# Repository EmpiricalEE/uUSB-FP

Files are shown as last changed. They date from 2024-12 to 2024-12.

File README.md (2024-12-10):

# Joulescope JS220 uUSB Front Panel

> ⚠️ This is a **read-only** mirror of a private SVN repository. See the [Product Page](https://www.tindie.com/products/empirical-ee/uusb-front-panel/) on Tindie.

The uUSB FP is a versatile panel for the [Joulescope JS220](https://www.joulescope.com/products/js220-joulescope-precision-energy-analyzer) power analyser that enables power measurement of any USB device.

## Key Features

- Multiple USB connector types supported:
    - USB Type-C
    - USB Type-A
    - Micro USB
    - Screw terminals for custom connections
- Supports any combination of input terminal and output terminal
- Compatible with Joulescope JS220
- Supports USB 2.0 High Speed (HS) data pass-through with minor performance impact

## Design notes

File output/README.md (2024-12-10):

## Introduction

- Name: BP1 (aka `Joulescope 220 Front Panel for USB powered loads`)
- Version:
	- PCB: v241112
	- BOM: Rev C
- Purpose: PCB manufacture and assembly

## PCB Manufacturing Specifications

- IPC-6011: Class 2
- Base Material: FR-4
- PCB Thickness: 1.6 mm ± 10 %
- Outline tolerance: 0.2 mm
- Layers: 4
- Outer Copper Weight: 1 oz
- Inner Copper Weight: 0.5 oz
- Impedance Control: No requirement
- PCB Color: Black
- Silkscreen Colour: White
- Via Covering: Tented
- Surface Finish: HASL (with lead)
- Mark on PCB on the rear (JLCPCB Remove Mark)

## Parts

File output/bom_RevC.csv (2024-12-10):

Reference | Value | Datasheet | Footprint | Qty | DNP | Description | MPN | Manufacturer | Order Code | Supplier | Critical
J1 | JS220 | https://mm.digikey.com/Volume0/opasdata/d220001/medias/docus/6129/tsm-1xx-xx-xxx-xx-x-xxx-x-mkt.pdf | Joulescope:JS220 | 1 |  | Joulescope 220 front panel outline and connector | TSM-103-01-S-DV-A | Samtec Inc. | TSM-103-01-S-DV-A-ND | Digi-Key
J2 | USB_B_In | https://www.cuidevices.com/product/resource/uj2-bv-1-th.pdf | Becquerel:USB_B_CUI_Devices_UJ2-BV-1-TH_Vertical | 1 |  | USB Type B connector | UJ2-BV-1-TH | CUI Devices | 102-4000-ND | Digi-Key
J3 | USB_B_Micro_In | https://gct.co/files/specs/usb3145-spec.pdf | Becquerel:USB_Micro-B_GCT_USB3145-30-1-A_Vertical | 1 |  | USB Micro Type B connector | USB3145-30-1-A | GCT | 2073-USB3145-30-1-ACT-ND | Digi-Key
J4 | USB_C_In | https://mm.digikey.com/Volume0/opasdata/d220001/medias/docus/5561/USB4145%20-%20Product%20Drawing.pdf | Becquerel:USB_C_Receptacle_GCT_USB4115-03-C | 1 |  | USB 2.0-only 24P Type-C Receptacle connector | UJ20-C-V-C-3-SMT-TR | Same Sky | 2223-UJ20-C-V-C-3-SMT-TR-ND | Digi-Key
J5 | Screw_In | https://www.we-online.com/katalog/datasheet/6912109100xx.pdf | Becquerel:TerminalBlock_Wuerth_691210910004-2.54-4P_1x04_P2.54mm_Horizontal | 1 |  | Generic screw terminal, single row, 01x04, script generated (kicad-library-utils/schlib/autogen/connector/) | 691210910004 | Würth Elektronik | 732-691210910004-ND | Digi-Key
J6 | USB_A_Out | https://app.adam-tech.com/products/download/data_sheet/195863/usb-a-s-vt-data-sheet.pdf | Becquerel:USB_A_Adam_Tech_USB-A-S-VT_Vertical | 1 |  | USB Type A connector | USB-A-S-VT | Adam Tech | 2057-USB-A-S-VT-ND | Digi-Key
J7 | USB_AB_Micro_Out | https://gct.co/files/specs/usb3106-spec.pdf | Becquerel:USB_Micro-AB_GCT_USB3106-30-0230-A_Vertical | 1 |  | USB Micro Type B connector | USB3106-30-0230-A | GCT | 2073-USB3106-30-0230-ACT-ND | Digi-Key
J8 | USB_C_Out | https://mm.digikey.com/Volume0/opasdata/d220001/medias/docus/5561/USB4145%20-%20Product%20Drawing.pdf | Becquerel:USB_C_Receptacle_GCT_USB4115-03-C | 1 |  | USB 2.0-only 24P Type-C Receptacle connector | UJ20-C-V-C-3-SMT-TR | Same Sky | 2223-UJ20-C-V-C-3-SMT-TR-ND | Digi-Key
J9 | Screw_Out | https://www.we-online.com/katalog/datasheet/6912109100xx.pdf | Becquerel:TerminalBlock_Wuerth_691210910004-2.54-4P_1x04_P2.54mm_Horizontal | 1 |  | Generic screw terminal, single row, 01x04, script generated (kicad-library-utils/schlib/autogen/connector/) | 691210910004 | Würth Elektronik | 732-691210910004-ND | Digi-Key

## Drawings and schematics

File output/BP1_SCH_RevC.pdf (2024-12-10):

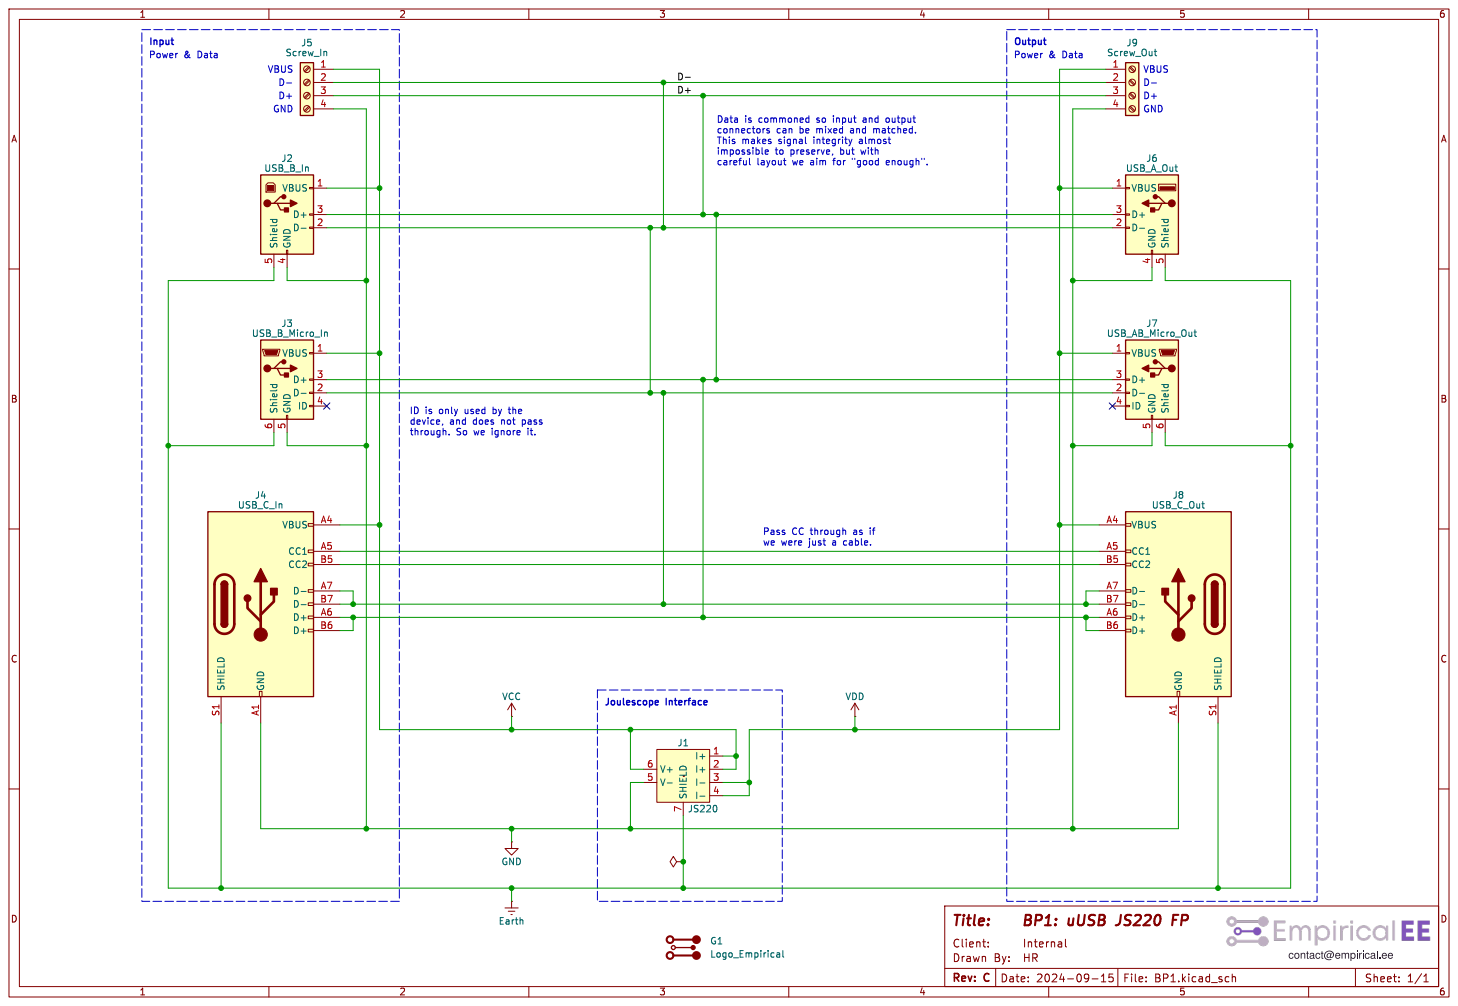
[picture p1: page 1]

ID is only used by the
device, and does not pass

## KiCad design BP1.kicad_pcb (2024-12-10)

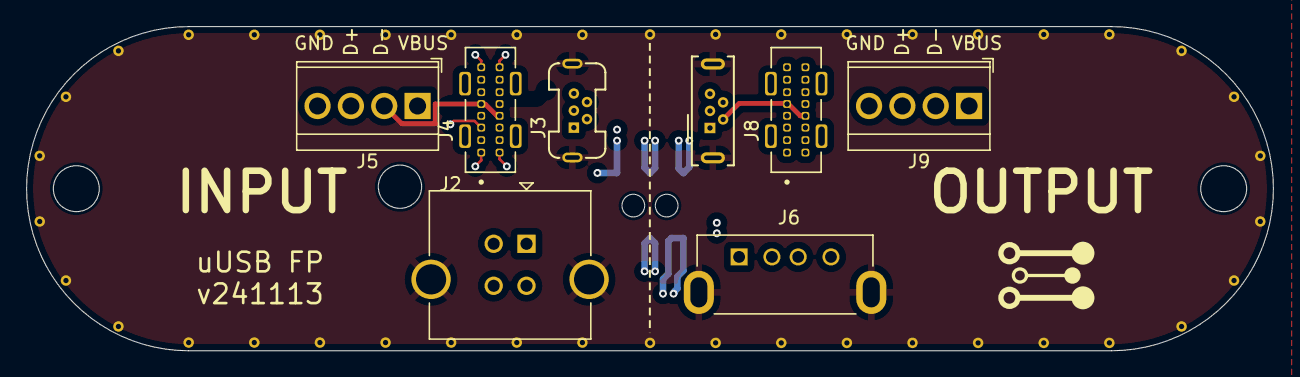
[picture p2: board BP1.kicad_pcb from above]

Board: 4 copper layers, 95.0 x 24.7 mm, 10 parts (0 on the bottom side), 8 nets.

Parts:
G1: Logo_Empirical; logo_empirical_7x5mm
J1: JS220
J2: USB_B_In; USB_B_CUI_Devices_UJ2-BV-1-TH_Vertical
J3: USB_B_Micro_In; USB_Micro-B_GCT_USB3145-30-1-A_Vertical
J4: USB_C_In; CUI_UJ20-C-V-C-3-SMT-TR
J5: Screw_In; TerminalBlock_Wuerth_691210910004-2.54-4P_1x04_P2.54mm_Hori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
J6: USB_A_Out; USB_A_Adam_Tech_USB-A-S-VT_Vertical
J7: USB_AB_Micro_Out; USB_Micro-AB_GCT_USB3106-30-0230-A_Vertical
J8: USB_C_Out; CUI_UJ20-C-V-C-3-SMT-TR
J9: Screw_Out; TerminalBlock_Wuerth_691210910004-2.54-4P_1x04_P2.54mm_Hori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

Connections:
/D+: J2.3 (D+), J3.3 (D+), J4.A6 (D+), J4.B6 (D+), J5.3, J6.3 (D+), J7.3 (D+), J8.A6 (D+), J8.B6 (D+), J9.3
/D-: J2.2 (D-), J3.2 (D-), J4.A7 (D-), J4.B7 (D-), J5.2, J6.2 (D-), J7.2 (D-), J8.A7 (D-), J8.B7 (D-), J9.2
Earth: J1.7 (SHIELD), J2.5 (Shield), J3.6 (Shield), J6.5 (Shield), J7.6 (Shield)
GND: J1.5 (V-), J2.4 (GND), J3.5 (GND), J4.A1 (GND), J4.A12 (GND), J4.B1 (GND), J4.B12 (GND), J5.4, J6.4 (GND), J7.5 (GND), J8.A1 (GND), J8.A12 (GND), J8.B1 (GND), J8.B12 (GND), J9.4
unnamed: J4.A5 (CC1), J8.A5 (CC1)
unnamed: J4.B5 (CC2), J8.B5 (CC2)
VCC: J1.1 (I+), J1.2 (I+), J1.6 (V+), J2.1 (VBUS), J3.1 (VBUS), J4.A4 (VBUS), J4.A9 (VBUS), J4.B4 (VBUS), J4.B9 (VBUS), J5.1
VDD: J1.3 (I-), J1.4 (I-), J6.1 (VBUS), J7.1 (VBUS), J8.A4 (VBUS), J8.A9 (VBUS), J8.B4 (VBUS), J8.B9 (VBUS), J9.1
